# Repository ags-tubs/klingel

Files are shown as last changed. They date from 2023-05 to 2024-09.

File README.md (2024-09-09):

# ags Klingel

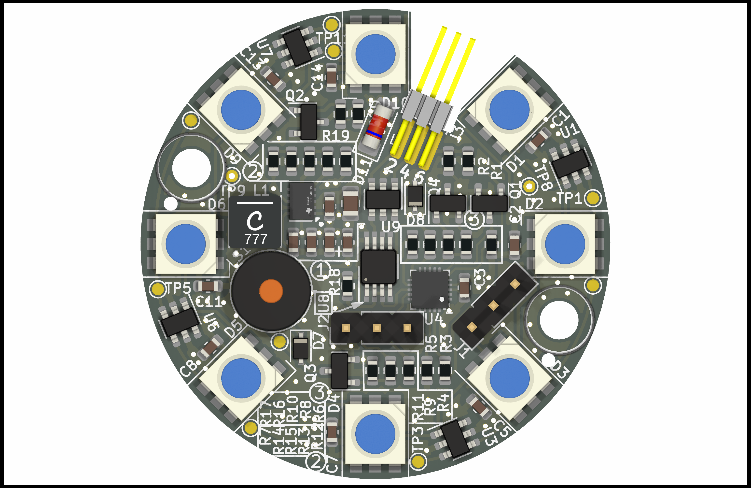
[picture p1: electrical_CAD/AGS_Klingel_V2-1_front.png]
PCB-front-view


Fancy Klingel designed by Max Nowka.
Features:
- 24V VCC
- Piezo
- WS2813 RGB LEDs
- RS485 Support (bsp. für Modbus)
- "Touch"
- mit dem Gehäuse mehr oder weniger vandalismussicher

## How to CMake

```
mkdir build
cd build
cmake ..
```

oder es kann auch die CMake-GUI verwendet werden, wo auch die Konfigurationsoptionen komfortabel geändert werden können.

## Programmieren

Es gibt einen rudimentären Bootloader. Dieser kann mittels `make programbl` über UPDI (Standardport `/dev/ttyUSB0`) geflasht werden.
Weiterhin gibt es eine Software, die danach über RS485 mittels `make program` (Standardport `/dev/ttyUSB1`) geflasht werden kann.

## Lizenz

[GPLv3](COPYING)

## Weitere Credits

Bootloaderimplementierung teilweise von Optiboot ~~geklaut~~inspiriert.

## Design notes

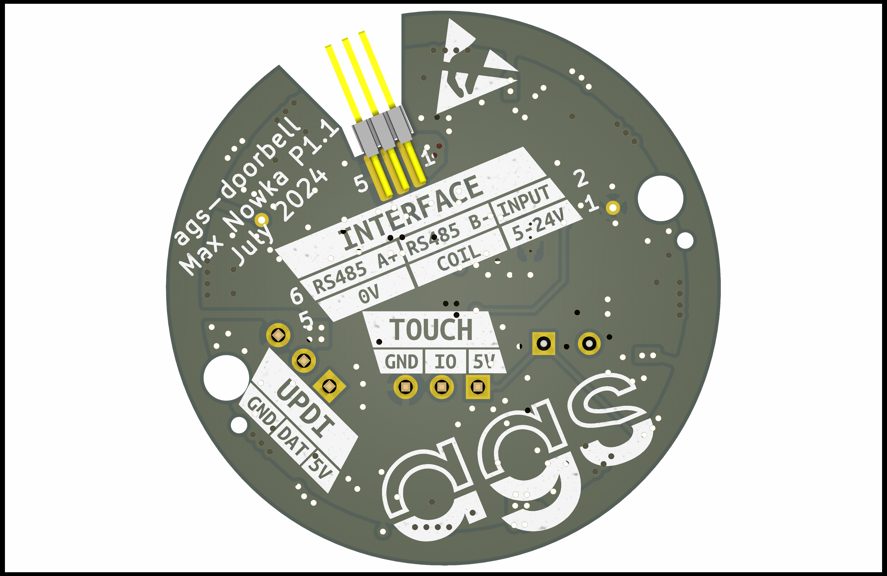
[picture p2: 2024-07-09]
electrical_CAD/AGS_Klingel_V2-1_back.png

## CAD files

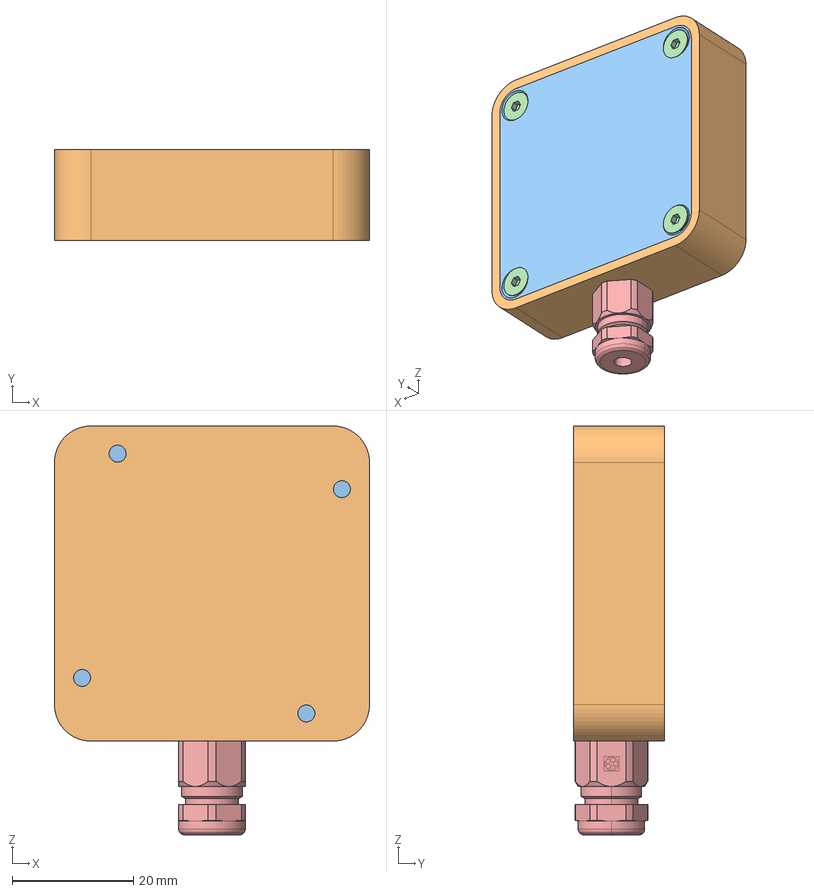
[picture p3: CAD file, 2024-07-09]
mechnical_CAD/klingel_asm_asm.stp
52.0 x 15.0 x 67.5 mm
01-GEHAEUSE
02-ABDECKUNG
DIN7991_M3X8 x 4
LAPP_SKINDICHT_M8_52001880
03-ISOLATOR
_AUTOSAVE-AGS_KLINGEL_V2_PCB
O-RING_44X1
TTP223
1X3_MALE_PIN_HEADER_ASM
DIN84_M3X5 x 2

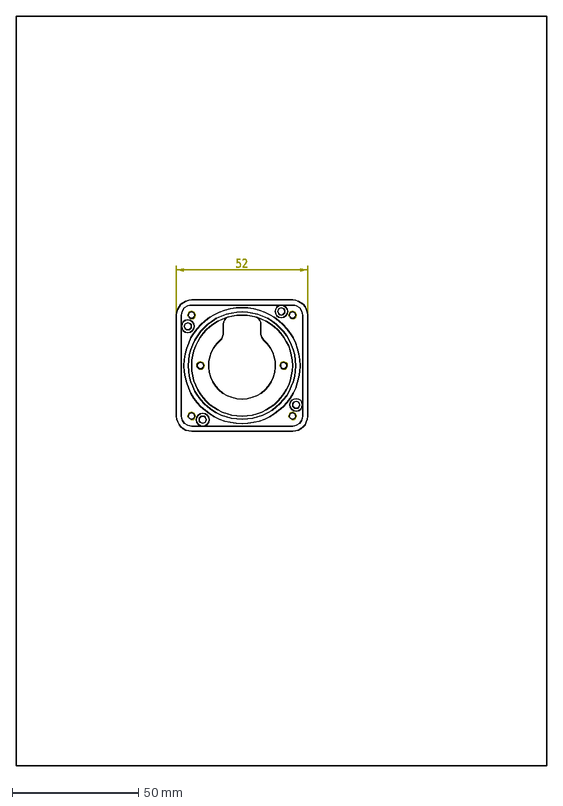
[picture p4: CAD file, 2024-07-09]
mechnical_CAD/gehaeuse_dxf.dxf
52

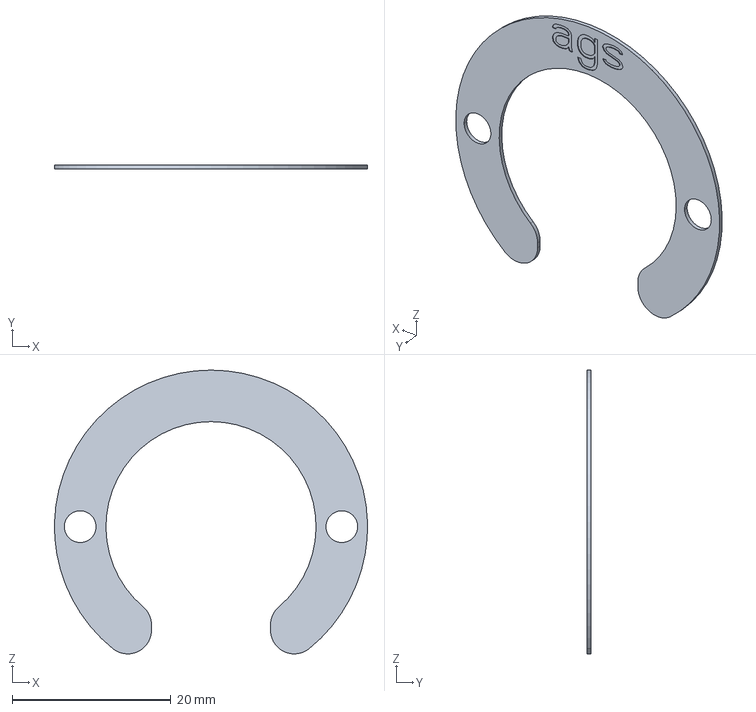
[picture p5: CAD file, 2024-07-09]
mechnical_CAD/03-isolator.stp
39.5 x 0.5 x 35.8 mm

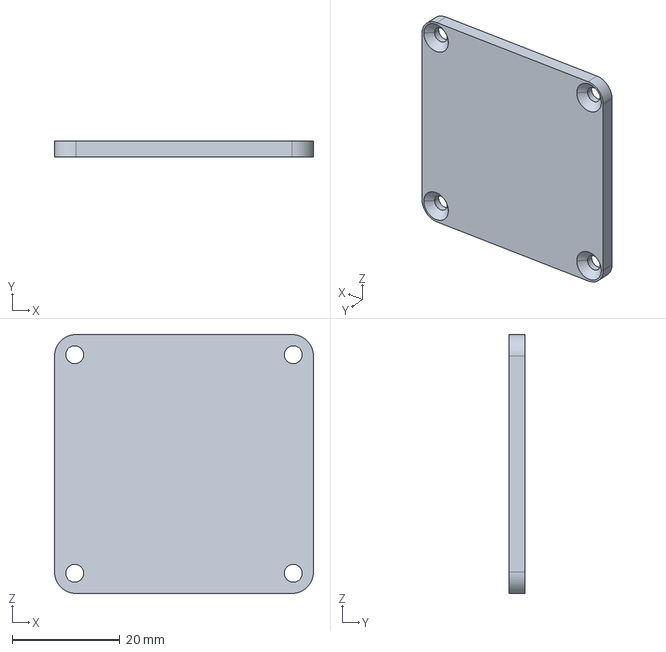
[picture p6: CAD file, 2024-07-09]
mechnical_CAD/02-fenster.stp
48.0 x 3.00 x 48.0 mm

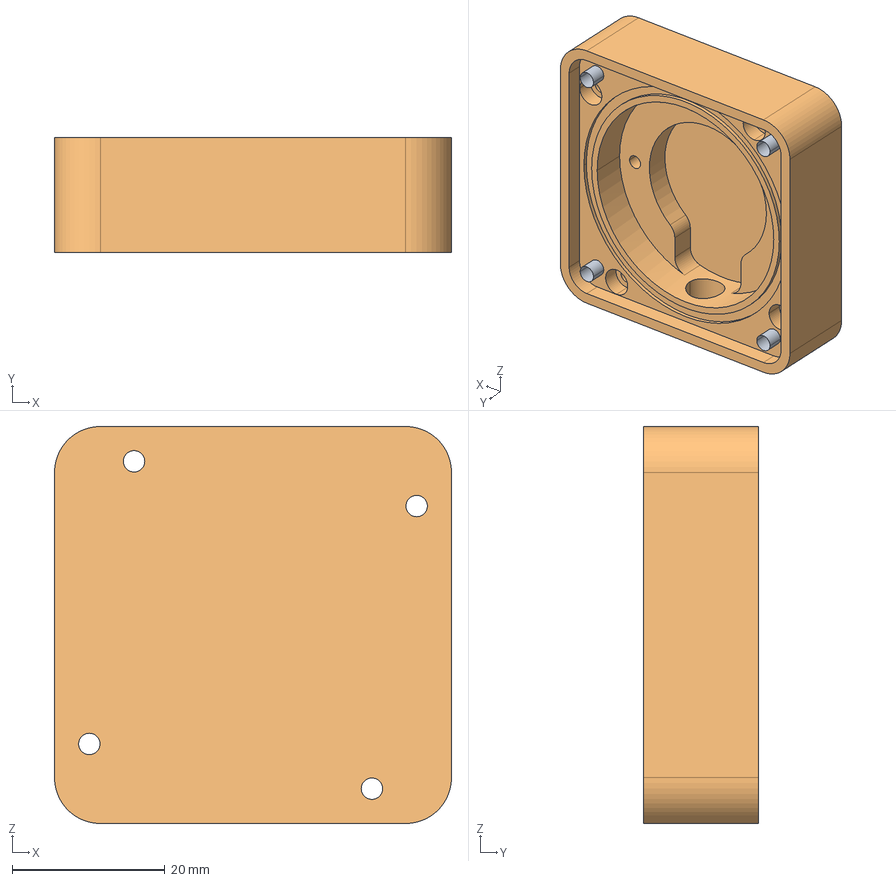
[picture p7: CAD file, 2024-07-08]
mechnical_CAD/01-gehaeuse.stp
52.0 x 15.0 x 52.0 mm

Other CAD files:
mechnical_CAD/03-isolator.stl

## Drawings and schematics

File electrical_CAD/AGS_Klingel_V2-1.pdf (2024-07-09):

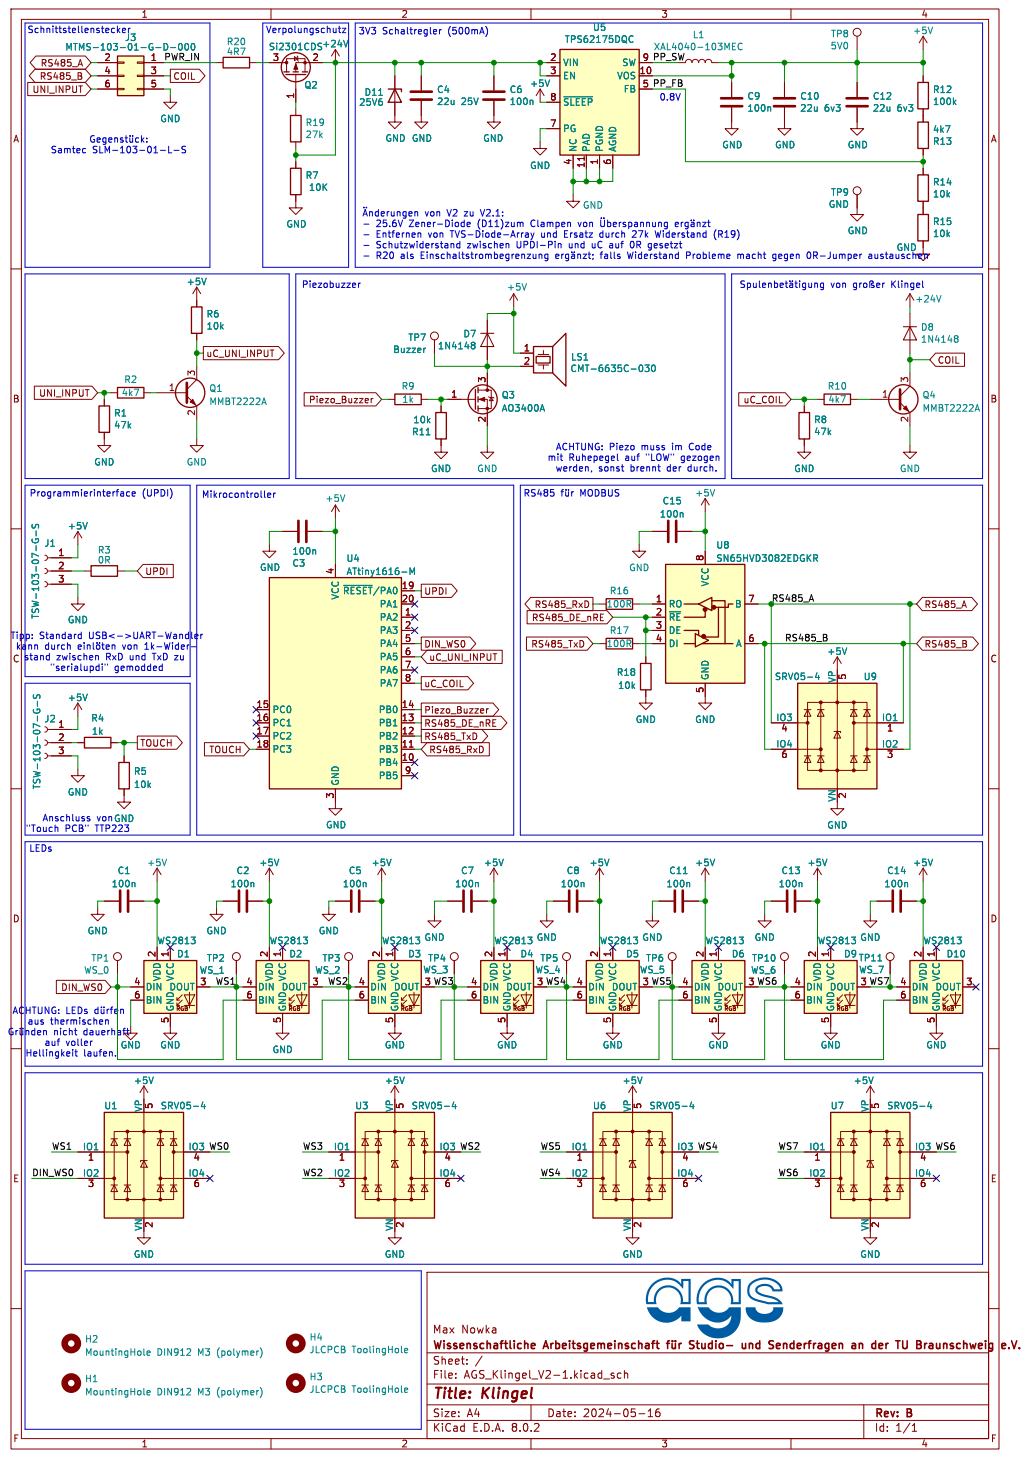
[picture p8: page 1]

6 PG 7 ~{SLEEP} 8 SW 9 +5V GND

1 VOS 10 PAD 11 VIN 2 EN 3 NC

ACHTUNG: Piezo muss im Code mit Ruhepegel auf "LOW" gezogen werden, sonst brennt der durch. Tipp: Standard USB<->UART-Wandler kann durch þÿeinlöten von 1k-Wider- stand zwischen RxD und TxD zu

5 BIN 6 D6 WS2813 RO 1 ~{RE} 2 DE 3 DI 4 GND

"Touch PCB" TTP223 ACHTUNG: LEDs þÿdürfen

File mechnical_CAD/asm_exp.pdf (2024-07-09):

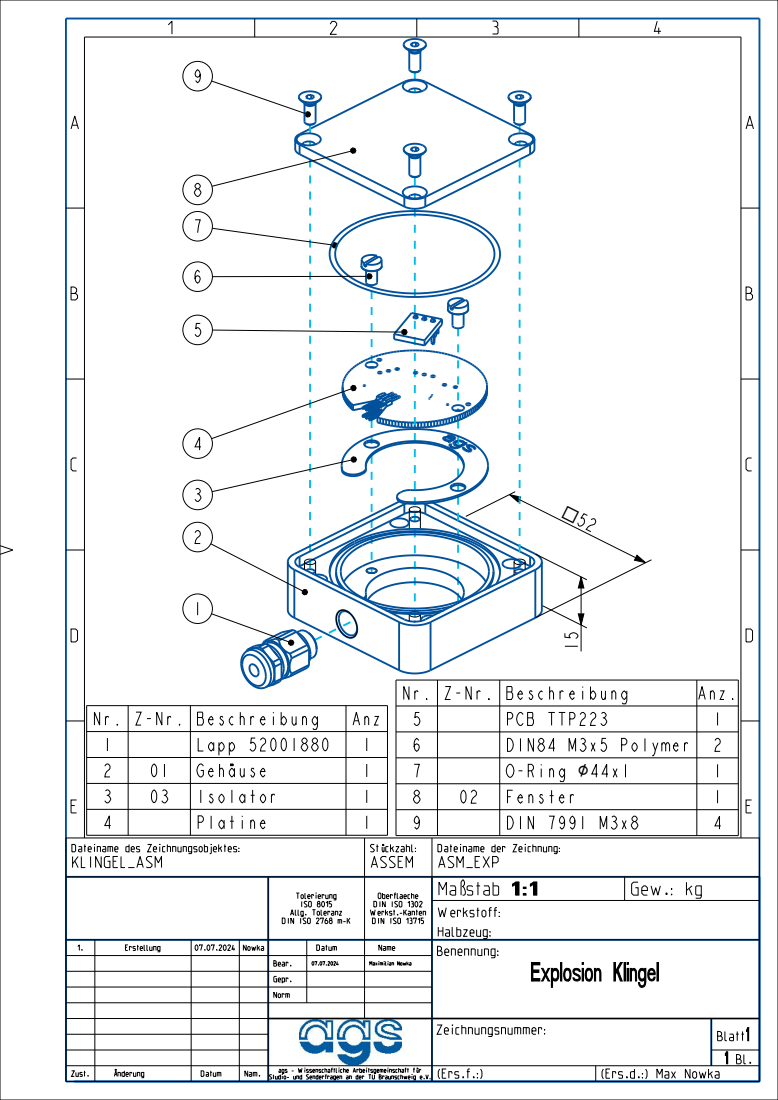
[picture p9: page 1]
Beschreibung; Anz; Lapp 52001880; Gehäuse; Isolator; Platine; Anz.; PCB TTP223; DIN84 M3x5 Polymer; O-Ring ⌀44x1; Fenster; DIN 7991 M3x8; Werkstoff: Halbzeug:

Dateiname des Zeichnungsobjektes: KLINGEL_ASM | | | Stückzahl: ASSEM | Dateiname der Zeichnung: ASM_EXP

Tolerierung ISO 8015 Allg. Toleranz DIN ISO 2768 m-K | Oberflaeche DIN ISO 1302 Werkst.-Kanten DIN ISO 13715 | Maßstab 1:1 | | Gew.: kg

1. | Erstellung | 07.07.2024 | Nowka | | Datum | Name | Benennung:

07.07.2024 | Maximilian Nowka | Explosion Klingel Bear.
Gepr.
Norm

Zeichnungsnummer: | Blatt1

Zust. | | Änderung | Datum | Nam. Studio- und Senderfragen an der TU Braunschweig e.V(Ers.f.:) | ags - Wissenschaftliche Arbeitsgemeinschaft für | (Ers.d.:) Max Nowka

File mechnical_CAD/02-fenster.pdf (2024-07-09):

A | A
1 | 2 | 3 | 4

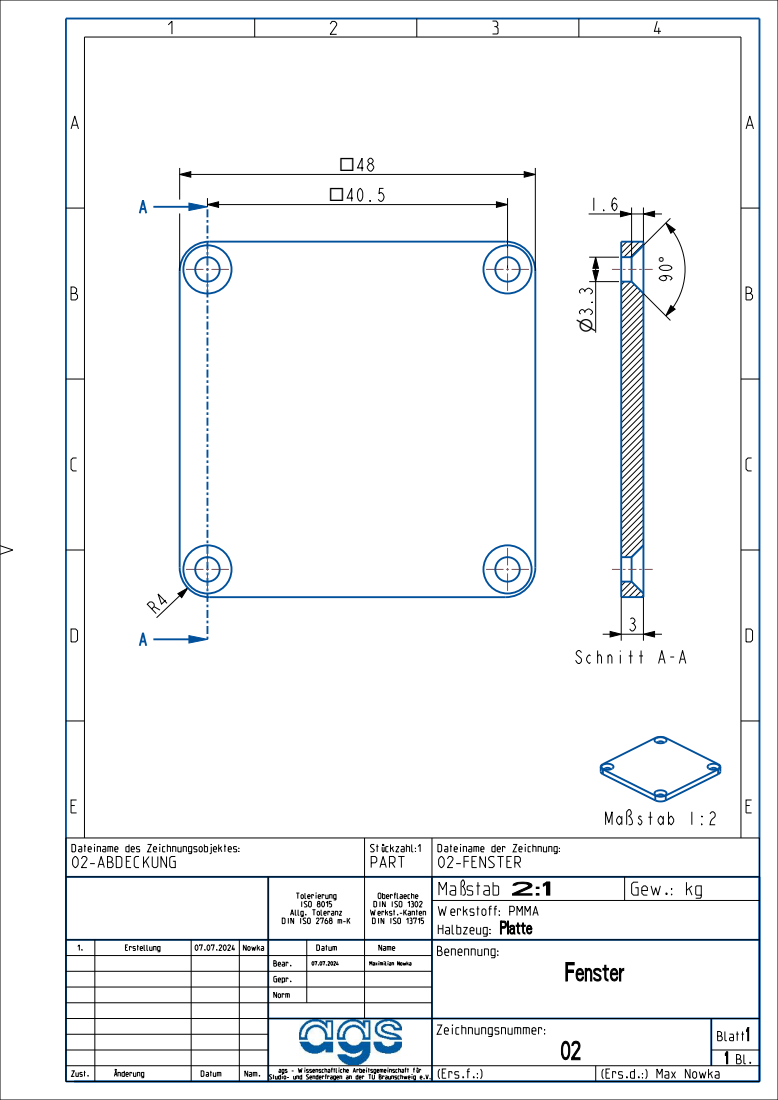
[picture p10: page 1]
PART; Tolerierung ISO 8015 Allg. Toleranz DIN ISO 2768 m-K; Oberflaeche DIN ISO 1302 Werkst.-Kanten DIN ISO 13715; Maßstab 2:1; Gew.: kg; Werkstoff: PMMA; Halbzeug: Platte 1.; Erstellung; Nowka; Datum; Name; Benennung:; Maßstab 1:2; Schnitt A-A

Dateiname des Zeichnungsobjektes: 02-ABDECKUNG | | Stückzahl:1 | Dateiname der Zeichnung: 02-FENSTER

07.07.2024 | Maximilian Nowka | Fenster Bear.
Gepr.
Norm

Zeichnungsnummer: 02 | Blatt1

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

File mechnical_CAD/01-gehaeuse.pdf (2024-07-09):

A | A
1 | 2 | 3 | 4

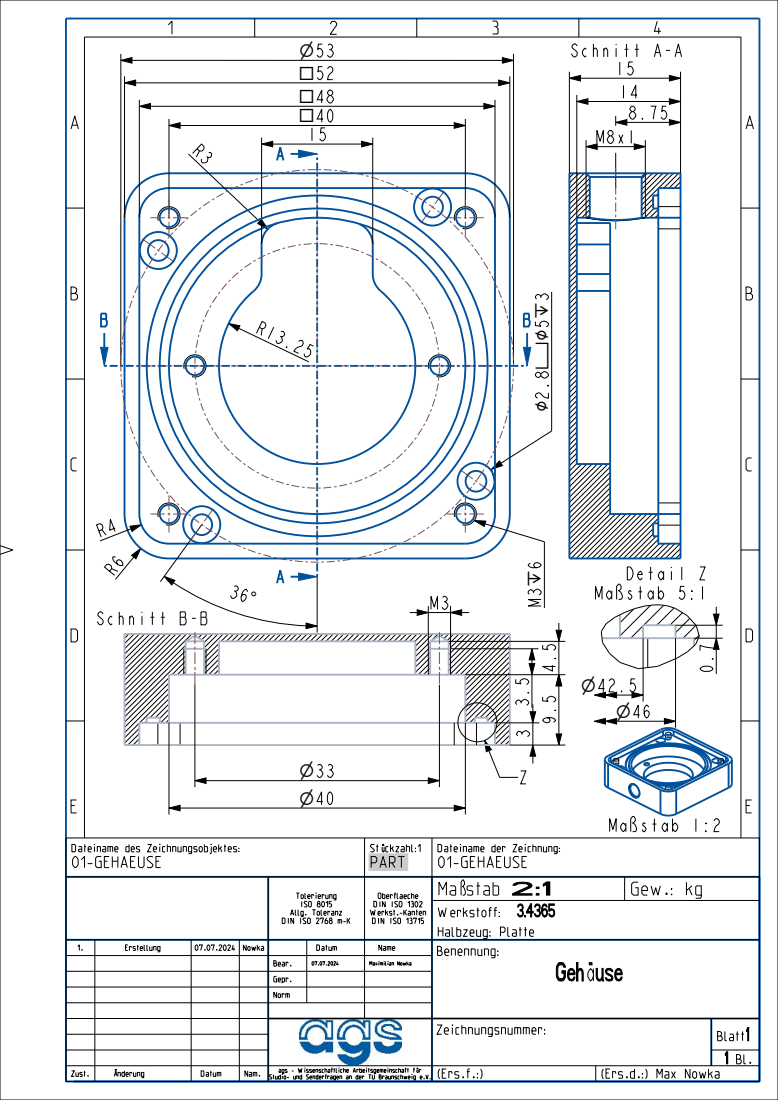
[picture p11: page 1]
Stückzahl:1 PART; Tolerierung ISO 8015 Allg. Toleranz DIN ISO 2768 m-K; Oberflaeche DIN ISO 1302 Werkst.-Kanten DIN ISO 13715; Maßstab 2:1; Gew.: kg; Werkstoff: 3.4365 Halbzeug: Platte; Maßstab 1:2; Schnitt A-A; Schnitt B-B; Detail Z Maßstab 5:1

Dateiname des Zeichnungsobjektes:
01-GEHAEUSE

Dateiname der Zeichnung:

1. | Erstellung | 07.07.2024 | Nowka | | Datum | Name | Benennung:

07.07.2024 | Maximilian Nowka | Gehäuse Bear.
Gepr.
Norm

Zeichnungsnummer: | Blatt1

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

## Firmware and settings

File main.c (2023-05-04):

#include <avr/interrupt.h>
#include <avr/io.h>
#include <avr/sleep.h>
#include <util/delay.h>

#define BAUD 38400
#include <util/setbaud.h>

typedef struct __attribute__((packed)) {
    uint8_t green;
    uint8_t red;
    uint8_t blue;
} color;

extern void display(color* pixels);

static color pixelSpinner[] = {
    { 0x00, 0x00, 0x00 },
    { 0x00, 0x00, 0x00 },
    { 0x00, 0x00, 0x00 },
    { 0x00, 0x00, 0x00 },
    { 0x00, 0x00, 0x00 },
    { 0x00, 0x00, 0x05 },
    { 0x00, 0x00, 0x25 },
    { 0x00, 0x00, 0x45 },
    { 0x00, 0x00, 0x00 },
    { 0x00, 0x00, 0x00 },
    { 0x00, 0x00, 0x00 },
    { 0x00, 0x00, 0x00 },
    { 0x00, 0x00, 0x00 },
    { 0x00, 0x00, 0x05 },
    { 0x00, 0x00, 0x25 },
};

static color off[] = {
    { 0x00, 0x00, 0x00 },
    { 0x00, 0x00, 0x00 },
    { 0x00, 0x00, 0x00 },
    { 0x00, 0x00, 0x00 },
    { 0x00, 0x00, 0x00 },
    { 0x00, 0x00, 0x00 },
    { 0x00, 0x00, 0x00 },
    { 0x00, 0x00, 0x00 },
};

static color on[] = {
    { 0xFF, 0xff, 0xff },
    { 0xFF, 0xff, 0xff },
    { 0xFF, 0xff, 0xff },
    { 0xFF, 0xff, 0xff },
    { 0xFF, 0xff, 0xff },
    { 0xFF, 0xff, 0xff },
    { 0xFF, 0xff, 0xff },
    { 0xFF, 0xff, 0xff },
};

void ring()
{
    PORTA.OUTSET = PIN7_bm;
    // see bottom of function
    TCA0.SINGLE.CTRLB = TCA_SINGLE_CMP0EN_bm | TCA_SINGLE_WGMODE_FRQ_gc;
    TCA0.SINGLE.CTRLA = TCA_SINGLE_ENABLE_bm;

    uint8_t loc = 7;
    for (int i = 0; i < 3 * 8; i++) {
        display(pixelSpinner + loc);
        loc = (loc + 1) % 8;
        _delay_ms(100);
    }
    display(off);

    PORTA.OUTCLR = PIN7_bm;
    TCA0.SINGLE.CTRLB = 0; // turn PWM override off, so we don't kill the piezo if it stays at 1
    TCA0.SINGLE.CTRLA = 0; // powersaving
}

static color dyn[] = {
    { 0x00, 0x00, 0x00 },
    { 0x00, 0x00, 0x00 },
    { 0x00, 0x00, 0x00 },
    { 0x00, 0x00, 0x00 },
    { 0x00, 0x00, 0x00 },
    { 0x00, 0x00, 0x00 },
    { 0x00, 0x00, 0x00 },
    { 0x00, 0x00, 0x00 },
};
static uint8_t cur = 0xa;
static uint8_t dir = 1;
void breathe()
{
    cur = cur + dir;
    for (int i = 0; i < 8; i++) {
        uint8_t downscale = cur / 2;
        dyn[i].red = cur;
        dyn[i].green = downscale < 5 ? 5 : downscale;
        dyn[i].blue = 0; // downscale < 5 ? 5 : downscale;
    }
    display(dyn);
    if (cur == 0x30) {
        dir = -1;
    } else if (cur == 0xa) {
        dir = 1;
    }
    for (int i = 0; i < 130 - cur; i++) {
        _delay_ms(1);
    }
}

inline void uart_setup()
{
    USART0.CTRLA = USART_DREIE_bm;
    USART0.CTRLB = USART_TXEN_bm;
    USART0.CTRLC = USART_CMODE_ASYNCHRONOUS_gc | USART_CHSIZE_8BIT_gc;

    USART0.BAUDH = 0;
    USART0.BAUDL = 116;
}

ISR(USART0_DRE_vect)
{
    USART0.TXDATAL = 0x31;
}

uint8_t ring_timeout = 0;
int main(void)
{
    PORTA.DIRSET = PIN4_bm | PIN7_bm;
    PORTB.DIRSET = PIN0_bm | PIN1_bm | PIN2_bm;
    TCA0.SINGLE.CMP0L = 22;
    TCA0.SINGLE.CMP0H = 1;

    uart_setup();
    sei();
    PORTB.OUTSET = PIN1_bm;
    USART0.TXDATAL = 0x31;

    while (1) {
        if (ring_timeout) {
            ring_timeout--;
        } else {
            if (VPORTC.IN & PIN3_bm) {
                ring();
                ring_timeout = 0x60;
            }
        }
        breathe();
    }
}

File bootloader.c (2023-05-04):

/**********************************************************/
/* Optiboot bootloader for Arduino                        */
/*                                                        */
/* http://optiboot.googlecode.com                         */
/*                                                        */
/* Arduino-maintained version : See README.TXT            */
/* http://code.google.com/p/arduino/                      */
/*  It is the intent that changes not relevant to the     */
/*  Arduino production environment get moved from the     */
/*  optiboot project to the arduino project in "lumps."   */
/*                                                        */
/* Heavily optimised bootloader that is faster and        */
/* smaller than the Arduino standard bootloader           */
/*                                                        */
/* Enhancements:                                          */
/*   Fits in 512 bytes, saving 1.5K of code space         */
/*   Higher baud rate speeds up programming               */
/*   Written almost entirely in C                         */
/*   Customisable timeout with accurate timeconstant      */
/*                                                        */
/* What you lose:                                         */
/*   Implements a skeleton STK500 protocol which is       */
/*     missing several features including EEPROM          */
/*     programming and non-page-aligned writes            */
/*   High baud rate breaks compatibility with standard    */
/*     Arduino flash settings                             */
/*                                                        */
/* Copyright 2013-2019 by Bill Westfield.                 */
/* Copyright 2010 by Peter Knight.                        */
/*                                                        */
/* This program is free software; you can redistribute it */
/* and/or modify it under the terms of the GNU General    */
/* Public License as published by the Free Software       */
/* Foundation; either version 2 of the License, or        */
/* (at your option) any later version.                    */
/*                                                        */
/* This program is distributed in the hope that it will   */
/* be useful, but WITHOUT ANY WARRANTY; without even the  */
/* implied warranty of MERCHANTABILITY or FITNESS FOR A   */
/* PARTICULAR PURPOSE.  See the GNU General Public        */
/* License for more details.                              */
/*                                                        */
/* You should have received a copy of the GNU General     */
/* Public License along with this program; if not, write  */
/* to the Free Software Foundation, Inc.,                 */
/* 59 Temple Place, Suite 330, Boston, MA  02111-1307 USA */
/*                                                        */
/* Licence can be viewed at                               */
/* http://www.fsf.org/licenses/gpl.txt                    */
/*                                                        */
/**********************************************************/

/**********************************************************/
/*                                                        */
/* Optional defines:                                      */
/*                                                        */
/**********************************************************/
/*                                                        */
/* BIGBOOT:                                               */
/* Build a 1k bootloader, not 512 bytes. This turns on    */
/* extra functionality.                                   */
/*                                                        */
/* BAUD_RATE:                                             */
/* Set bootloader baud rate.                              */
/*                                                        */
/* LED_START_FLASHES:                                     */
/* Number of LED flashes on bootup.                       */
/*                                                        */
/* LED_DATA_FLASH:                                        */
/* Flash LED when transferring data. For boards without   */
/* TX or RX LEDs, or for people who like blinky lights.   */
/*                                                        */
/* TIMEOUT_MS:                                            */
/* Bootloader timeout period, in milliseconds.            */
/* 500,1000,2000,4000,8000 supported.                     */
/*                                                        */
/* UART:                                                  */
/* UART number (0..n) for devices with more than          */
/* one hardware uart (644P, 1284P, etc)                   */
/*                                                        */
/**********************************************************/

/**********************************************************/
/* Version Numbers!                                       */
/*                                                        */
/* Arduino Optiboot now includes this Version number in   */
/* the source and object code.                            */
/*                                                        */
/* Version 3 was released as zip from the optiboot        */
/*  repository and was distributed with Arduino 0022.     */
/* Version 4 starts with the arduino repository commit    */
/*  that brought the arduino repository up-to-date with   */
/*  the optiboot source tree changes since v3.            */
/*    :                                                   */
/* Version 9 splits off the Mega0/Xtiny support.          */
/*  This is very different from normal AVR because of     */
/*  changed peripherals and unified address space.        */
/*                                                        */
/* It would be good if versions implemented outside the   */
/*  official repository used an out-of-seqeunce version   */
/*  number (like 104.6 if based on based on 4.5) to       */
/*  prevent collisions.  The CUSTOM_VERSION=n option      */
/*  adds n to the high version to facilitate this.        */
/*                                                        */
/**********************************************************/
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

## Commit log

2023-05-04 beeper now doesn't kill itself
    [main.c]
2023-05-04 Added necessary programming fuse
2024-07-08 Upload New File
    [01-gehaeuse.stp]
2024-09-10 adding gerber files
    [AGS_Klingel_V2-1-B_Cu.gbr, AGS_Klingel_V2-1-B_Mask.gbr, AGS_Klingel_V2-1-B_Paste.gbr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]
